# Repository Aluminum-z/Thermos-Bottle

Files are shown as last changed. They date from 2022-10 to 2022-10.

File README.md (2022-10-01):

# Thermos-Bottle
有点鸡肋的恒温杯(盖)第一版, 功率有点小，380ml水需要4h才能够下降10℃ ╮(╯▽╰)╭

## 1. 设计
### 1.1 结构
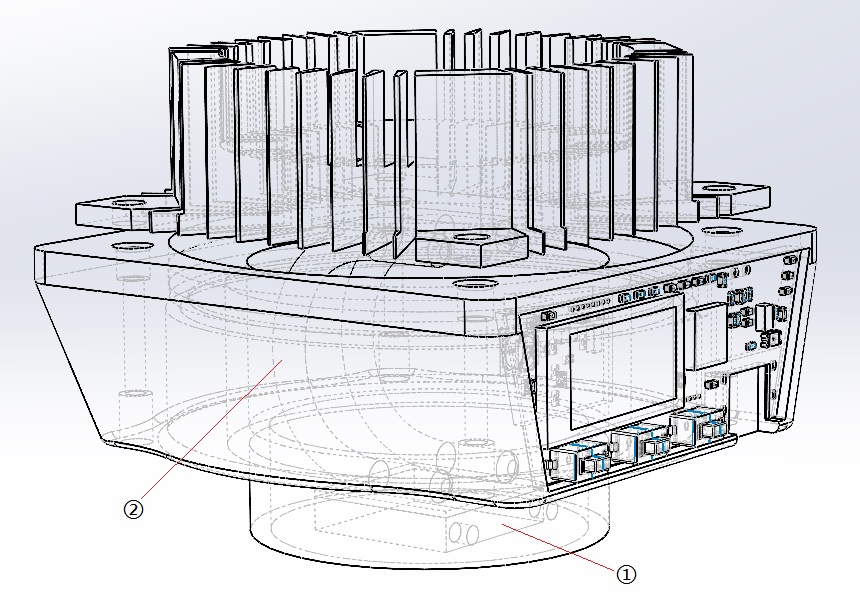
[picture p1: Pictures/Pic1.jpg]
杯盖的3D图


恒温杯盖的结构如上图，其中①所指的方块为半导体制冷片，②为热管。其原理很简单，制冷片的上方与热管紧贴，下方与杯盖内部的金属部分紧贴(①所指的圆柱突出部分在杯子盖起时会深入保温杯内部)。  
1. 当制冷片正向通电时，其下方从杯内吸收热量，上方从杯外放出热量，保温杯处于制冷模式。
2. 当制冷片反向通电时，其上方从杯外吸收热量，下方从杯内放出热量，保温杯处于制热模式。

### 1.2 硬件
电路框图

电路如上图，半导体制冷片串联电感使其变为感性负载，由全桥驱动芯片DRV8837驱动(~~比较便宜~~实际电路中使用两片并联以降低温升)，驱动方式类似于Buck降压电路，当全桥芯片导通时经由制冷片给电感充电，当全桥芯片关断(两输出引脚同时接地，类似同步整流)时由电感给半导体制冷片续流，使得制冷片在开关周期内能够保持一个较为稳定的电流。

注：电路板中的0Ω电阻R7原为复位按钮，请勿焊接。

### 1.3 软件
软件主要分为三个线程，UI线程、Main线程和Idle线程。UI负责处理按键消息和绘制用户界面；Main线程负责定时读取温度、读取输出电压、计算输出功率、根据当前温度调整输出占空比和将相关参数发给UI等工作；Idle线程负责按键的扫描工作。

## 2. 使用说明
### 2.1 界面
界面设计图  
界面设计如上图，其中：
- 左侧为半导体制冷片的工作状态及其两端温度，图中下冷上热三角指向上方即处于制冷状态；
- 进度条TE为半导体制冷片的输出占空比；
- 进度条FN为风扇的输出占空比；
- 右上角STAT处显示当前的工作状态，ON为工作中，OFF为停止；
- 右上角MOD处显示当前的工作模式，STAT为恒温模式，MXC为最大功率制冷模式，MXH为最大功率制热模式；
- 右上角VAL处显示恒温模式的温度设定值；
- 右下角5.0V显示当前的输入电压；
- 右下角3.0W显示当前的制冷片功率(估计值)。

### 2.2 操作
电路板上共有三个按键，从左至右分别“模式”，“加”和“减”；
- 长按“模式”后，进入模式设置状态，此时按下“加”或“减”按键可在“恒温”、“最大制冷功率”和“最大制热功率”间循环切换，模式设置完成后，再次点击“模式”按钮退出；
- 在非模式设置状态下，短按“模式”按钮可以切换当前的工作状态(ON/OFF)；
- 在非模式设置状态下，且当前模式为恒温模式时，点击“加”或“减”按钮可以调整恒温温度，长按“加”或“减”可以快速调整恒温温度。

## 3. 其他
### 3.1 参数
- 电压：5.0V
- 电流：2.0A Max
- 最大制冷功率：8W

### 3.2 待办
- 改进电路设计：
  - 增加快充的支持
  - 使用更大功率的制冷片
  - 调整功率元件至单独的铝基板，并使其能够贴在散热片上
- 改进结构设计：
  - 加一个上盖
  - 解决制冷模式下盖子内部积水的问题
  - 解决当保温杯内的水没有接触杯盖时制冷效率低的问题
  - 解决制热效率低的问题

### 3.3 实物图
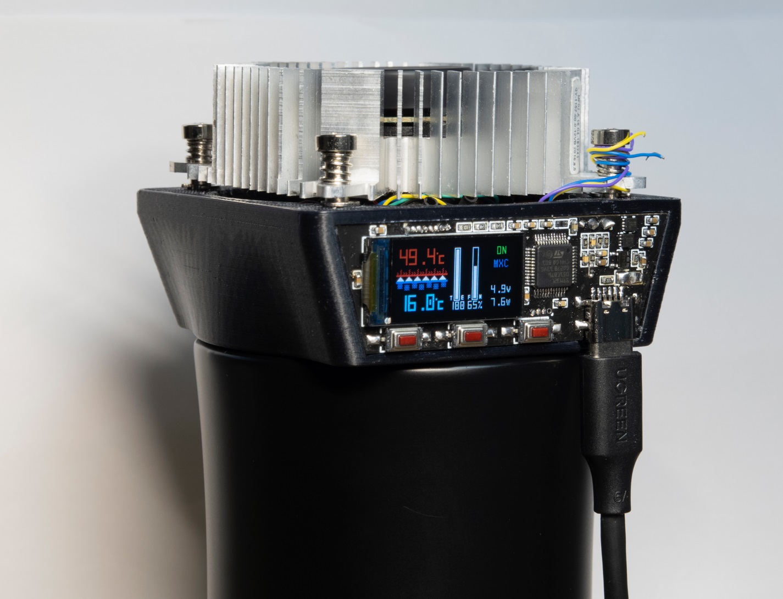
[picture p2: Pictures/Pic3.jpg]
实物图


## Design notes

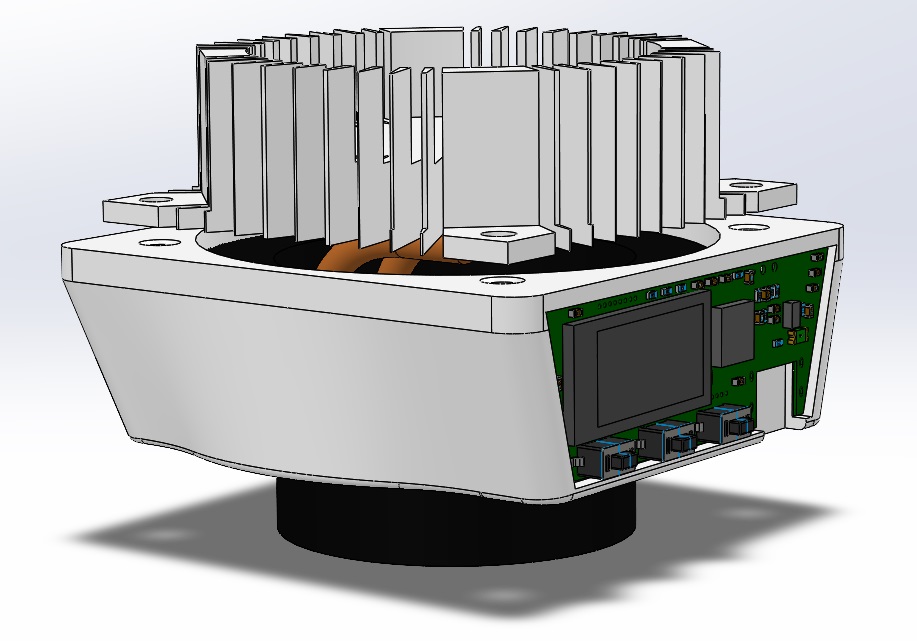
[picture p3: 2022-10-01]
Pictures/Pic2.jpg

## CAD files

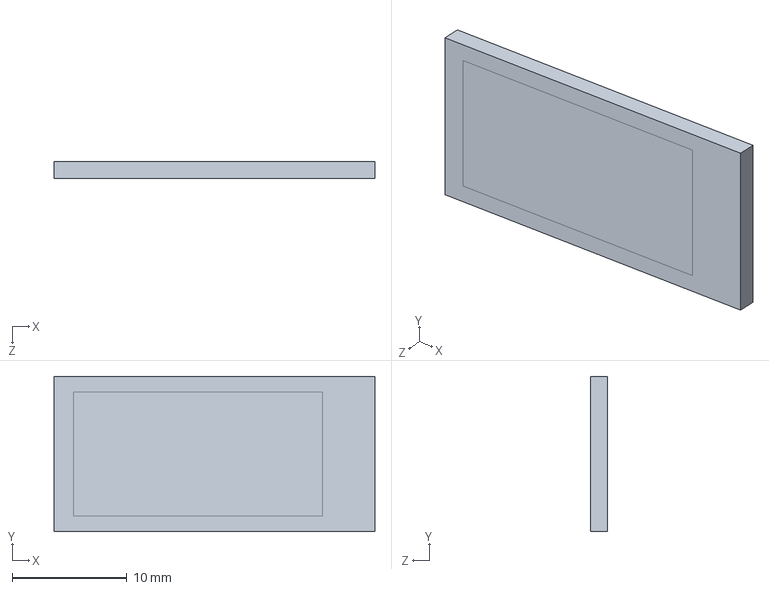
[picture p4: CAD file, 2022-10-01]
Hardware/Construction/LCD.SLDPRT
28.0 x 13.5 x 1.50 mm

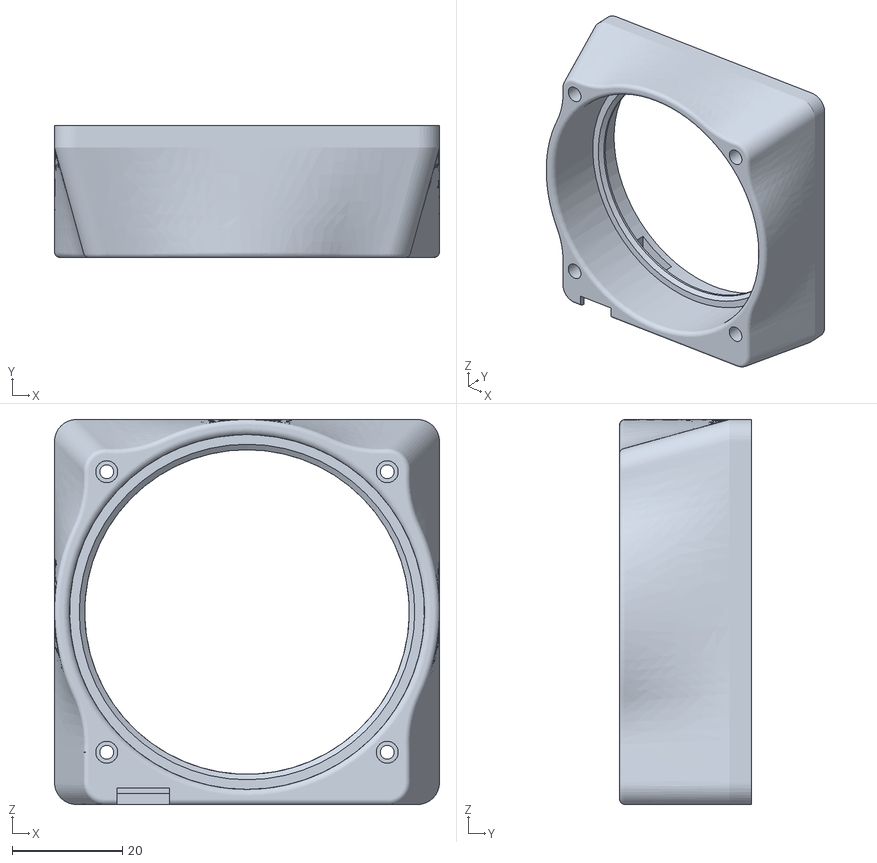
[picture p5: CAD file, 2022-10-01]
Hardware/Construction/Output/LidBottomV2P1.STL
70.0 x 24.0 x 70.0

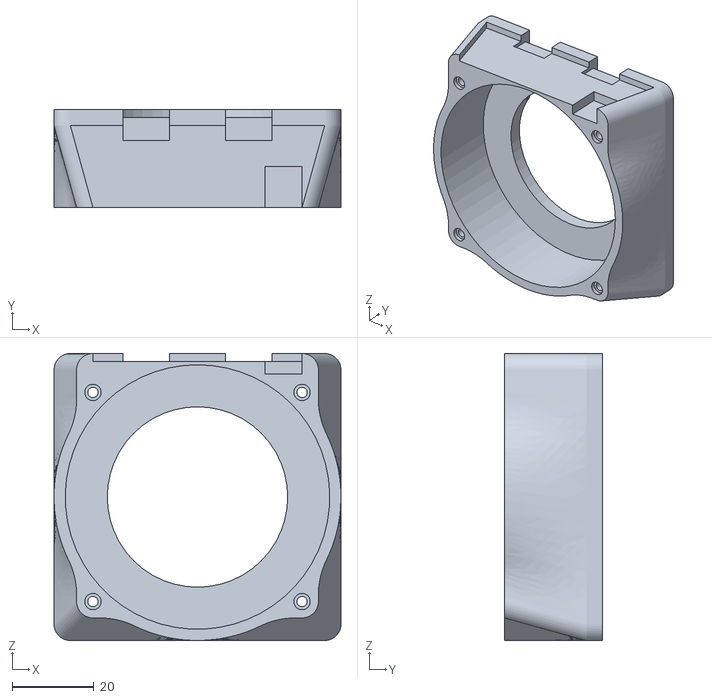
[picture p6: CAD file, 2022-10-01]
Hardware/Construction/Output/LidBottom.STL
70.0 x 24.0 x 70.0

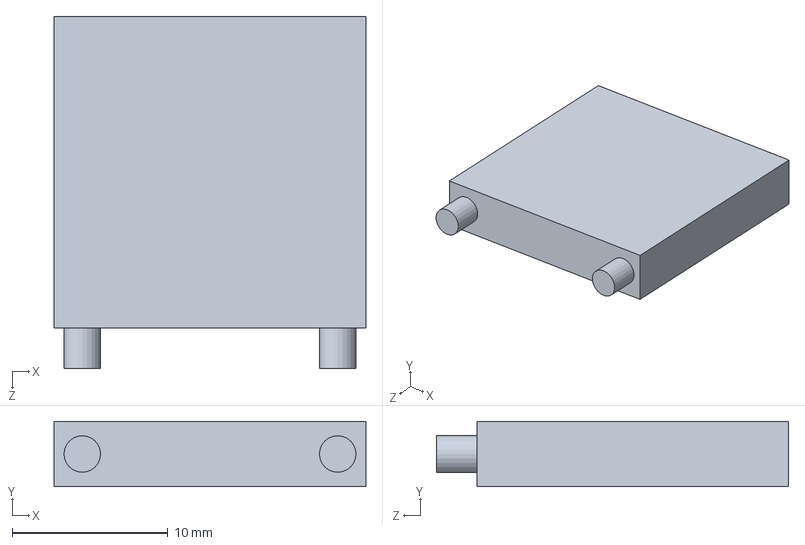
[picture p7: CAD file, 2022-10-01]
Hardware/Construction/TE.SLDPRT
20.0 x 4.20 x 22.6 mm

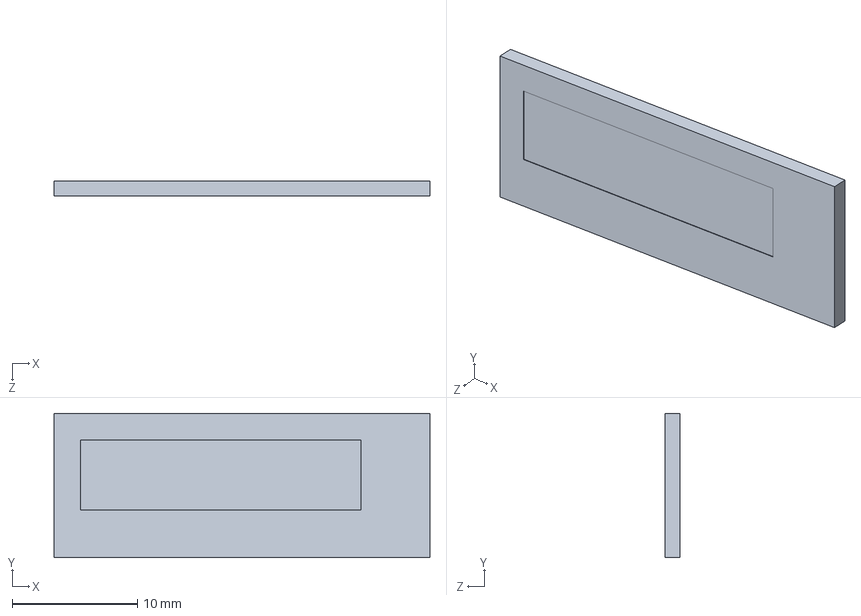
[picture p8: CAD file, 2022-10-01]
Hardware/Construction/OLED.SLDPRT
30.0 x 11.5 x 1.20 mm

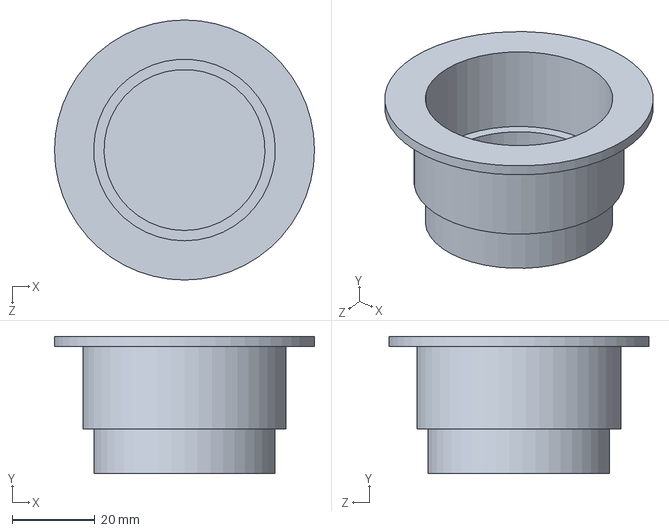
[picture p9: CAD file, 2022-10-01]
Hardware/Construction/LidBase.SLDPRT
63.0 x 33.3 x 63.0 mm

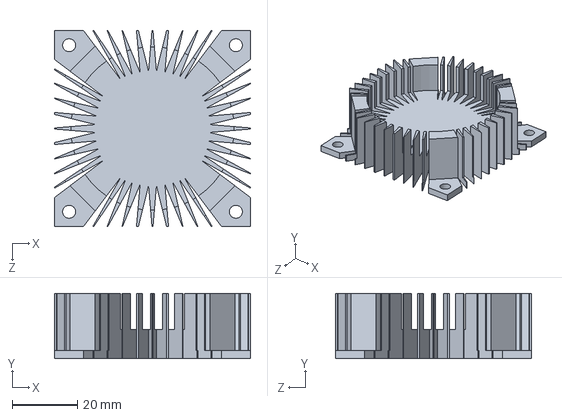
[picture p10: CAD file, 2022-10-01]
Hardware/Construction/Cooler.SLDPRT
60.0 x 20.0 x 60.0 mm

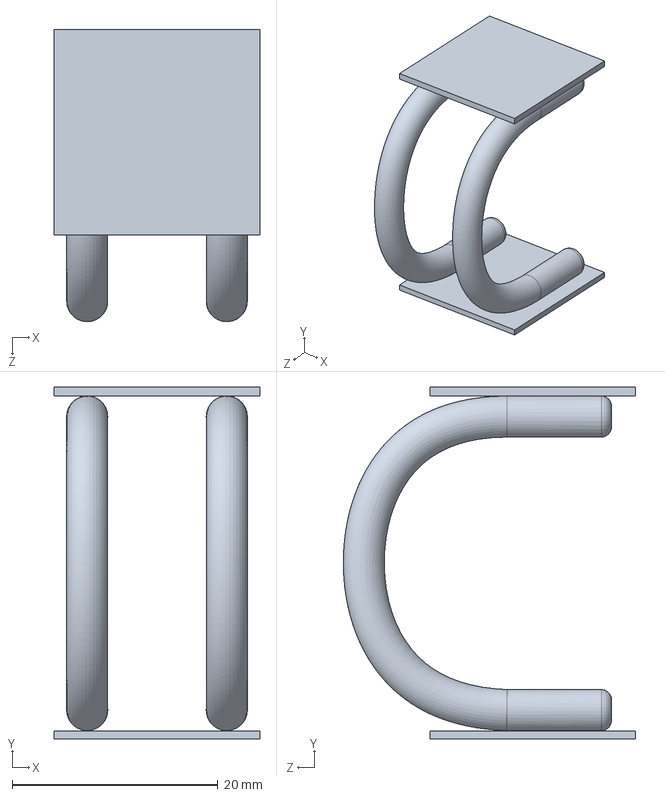
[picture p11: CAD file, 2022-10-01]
Hardware/Construction/Heat-Pipe.SLDPRT
20.0 x 34.3 x 28.4 mm

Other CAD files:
Hardware/Construction/LidBottom.SLDPRT
Hardware/Construction/LidBottomV2P1.SLDPRT

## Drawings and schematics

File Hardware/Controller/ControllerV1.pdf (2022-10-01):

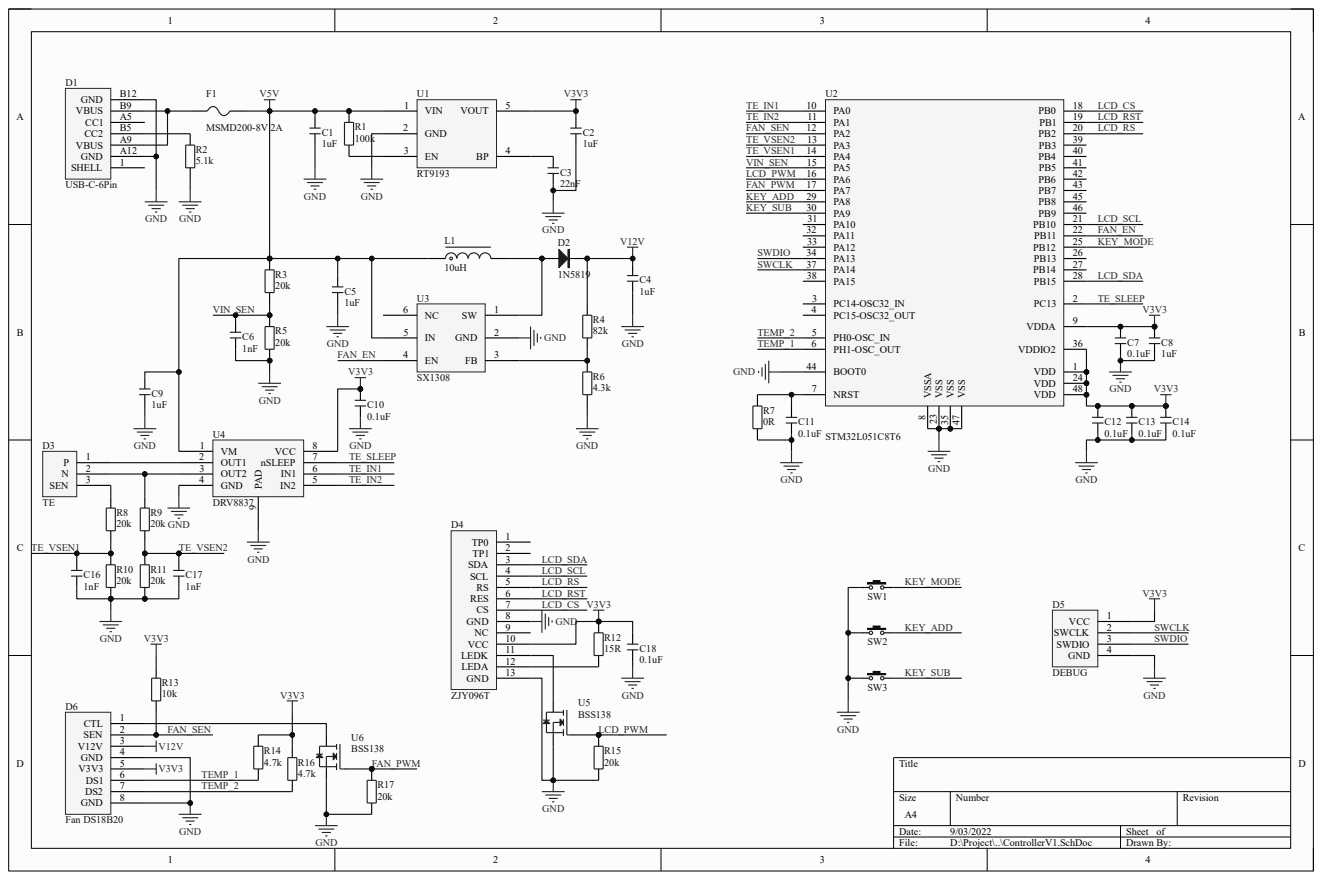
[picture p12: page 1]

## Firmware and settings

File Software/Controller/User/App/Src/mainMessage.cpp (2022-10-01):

/**************************************************************
 * @file    mainMessage.cpp
 * @brief   Message manager for main thread.
 * @author  Alzn
 * @date    2022-09-04
 *************************************************************/

#include "FreeRTOS.h"
#include "timers.h"

#include "deviceManager.hpp"
#include "mainMessage.hpp"
#include "pid.hpp"

#include <cmath>

/**
 * @brief   Callback function for main timer.
 * @author  Alzn
 * @date    2022-09-04
 */
static void mainTimerCallback(TimerHandle_t xTimer) {
  MainMessage &mainMsg = MainMessage::getInstance();
  mainMsg.send(MainMessage::MsgType::MainTimer, 0);
}

class MainMsgHandler {
private:
  enum TickDiv {
    TickTemp,
    TickPwrOut = 5,
    TickPwrIn = 9,
    TickMax = 10,
  };

private:
  TimerHandle_t mTimerHandle;

  uint16_t mTick;

  float mVolIn;
  float mCurTe;

  float mTempBtm;
  float mTempTop;

  bool mIsPwrEnabled;
  WorkMode mWorkMode;
  float mCfgTemp;

  Pid<float> mPidTec;
  TecMode mTecMode;

  bool mIsUiSynced;

private:
  MainMsgHandler &operator=(const MainMsgHandler &) = delete;
  MainMsgHandler(const MainMsgHandler &) = delete;
  MainMsgHandler() {
    mIsPwrEnabled = false;
    mTick = 0;
    mIsUiSynced = false;
  }

  void restartMainTimer(void) {
    xTimerStart(mTimerHandle, 0);
  }

  void sendValueToUI(UiMessage::MsgType msgType, float value1, float value2) {
    UiMessage &uiMsg = UiMessage::getInstance();
    UiMessage::MsgDataFloat msgData;
    msgData.data1 = value1;
    msgData.data2 = value2;
    uiMsg.send(msgType, msgData);
  }

  void setTecMode(TecMode mode) {
    if (mTecMode == mode) {
      return;
    }
    mTecMode = mode;
    DeviceManager &deviceManager = DeviceManager::getInstance();
    Tec &tec = deviceManager.getTec();
    tec.setMode(mTecMode);
    UiMessage &uiMsg = UiMessage::getInstance();
    uiMsg.send(UiMessage::MsgType::TecMode, mTecMode);
  }

public:
  static MainMsgHandler &getInstance(void) {
    static MainMsgHandler instance;
    return instance;
  }

  void init(void) {
    /* Variable */
    mVolIn = 0.0f;
    mCurTe = 0.0f;
    mTempBtm = 0.0f;
    mTempTop = 0.0f;

    mPidTec.setFactor(0.05f, 0.0005f, 0.02f);
    mPidTec.setCtrlValLimit(-1.0f, 1.0f);
    mPidTec.reset(0.0f);

    mTecMode = TecMode::BtmCoolTopHeat;
    mWorkMode = WorkMode::Thermostat;
    mCfgTemp = 20.0f;
    mIsUiSynced = false;
    /* Hardware */

    /* Timer */
    mTimerHandle = xTimerCreate("Main", pdMS_TO_TICKS(100), pdFALSE, nullptr, mainTimerCallback);
    restartMainTimer();
  }

  void mainTimerHandler(void) {
    mTick++;
    if (mTick >= TickMax) {
      mTick = 0;
    }

    restartMainTimer();

    if (!mIsUiSynced) {
      UiMessage &uiMsg = UiMessage::getInstance();
      uiMsg.send<UiMessage::MsgDataModeAndValue>(UiMessage::MsgType::WorkModeAndValue, {mCfgTemp, mWorkMode});
    }

    DeviceManager &deviceManager = DeviceManager::getInstance();
    Adc &adc = deviceManager.getAdc();
    if (!adc.getIsConverting()) {
      adc.start();
    }
    if (mTick == TickPwrIn) {
      sendValueToUI(UiMessage::MsgType::PowerIn, mVolIn, mCurTe);
    }

    Ds18b20 &tempsenTop = deviceManager.getTempSenTop();
    Ds18b20 &tempSenBtm = deviceManager.getTempSenBtm();
    mTempTop = tempsenTop.readTemp();
    mTempBtm = tempSenBtm.readTemp();
    if (mTick == TickTemp) {
      sendValueToUI(UiMessage::MsgType::Temperatures, mTempTop, mTempBtm);
    }

    float fanPwr = 0.0f;
    float tecPwr = 0.0f;
    if (!mIsPwrEnabled) {
      tecPwr = 0.0f;
      fanPwr = 0.0f;
    } else {
      mPidTec.setMeaVal(mTempBtm);
      if (mTecMode == TecMode::BtmCoolTopHeat) {
        if (mPidTec.getCtrlVal() > 0.01f) {
          setTecMode(TecMode::BtmHeatTopCool);
        }
      } else {
        if (mPidTec.getCtrlVal() < -0.01f) {
          setTecMode(TecMode::BtmCoolTopHeat);
        }
      }
      tecPwr = fabsf(mPidTec.getCtrlVal());
      if (mTecMode == TecMode::BtmCoolTopHeat) {
        const float maxTemperature = 60.0f;
        const float fanThreshold = 30.0f;
        if (mTempTop < fanThreshold) {
          fanPwr = 0.0f;
        } else {
          fanPwr = (mTempTop - fanThreshold) * (1.0f / (maxTemperature - fanThreshold));
          if (fanPwr > 1.0f) {
            fanPwr = 1.0f;
          }
        }
      } else {
        const float minTemperature = 0.0f;
        const float fanThreshold = 20.0f;
        if (mTempTop > fanThreshold) {
          fanPwr = 0.0f;
        } else {
          fanPwr = (fanThreshold - mTempTop) * (1.0f / (fanThreshold - minTemperature));
          if (fanPwr > 1.0f) {
            fanPwr = 1.0f;
          }
        }
      }
    }
    Tec &tec = deviceManager.getTec();
    tec.setDutyCycle(tecPwr);
    Fan &fan = deviceManager.getFan();
    fan.setDutyCycle(fanPwr);

    if (mTick == TickPwrOut) {
      sendValueToUI(UiMessage::MsgType::PowerOut, tecPwr, fanPwr);
    }
  }

  void adcConvCpltHandler(void) {
    DeviceManager &deviceManager = DeviceManager::getInstance();
    Adc &adc = deviceManager.getAdc();
    adc.convCpltCallBack();
    mVolIn = adc.getValue(Adc::AdcValVin);
    mCurTe = adc.getValue(Adc::AdcValPwr);
  }

  void setIsPwrEnabled(bool isEnabled) {
    if (mIsPwrEnabled == isEnabled) {
      return;
    }
    mIsPwrEnabled = isEnabled;
    if (isEnabled) {
      switch (mWorkMode) {
        case WorkMode::Thermostat:
          mPidTec.setCfgMeaVal(mCfgTemp);
          break;

        case WorkMode::MaxPwrCool:
          mPidTec.setCfgMeaVal(0.0f);
          break;

        case WorkMode::MaxPwrHeat:
          mPidTec.setCfgMeaVal(80.0f);
          break;

        default:
          break;
      }
    }
    mPidTec.reset(0.0f);
    UiMessage &uiMsg = UiMessage::getInstance();
    uiMsg.send(UiMessage::MsgType::PowerIsEnable, isEnabled);
  }

  void setWorkMode(WorkMode mode) {
    if (mWorkMode == mode) {
      return;
    }
    mWorkMode = mode;
    setIsPwrEnabled(false);
    UiMessage &uiMsg = UiMessage::getInstance();
    uiMsg.send<UiMessage::MsgDataModeAndValue>(UiMessage::MsgType::WorkModeAndValue, {mCfgTemp, mWorkMode});
  }

  void setCtrlValue(float value) {
    if (mWorkMode != WorkMode::Thermostat) {
      return;
    }
    const float maxTemp = 80.0f;
    const float minTemp = 0.0f;
    if (value > maxTemp) {
      value = maxTemp;
    }
    if (value < minTemp) {
      value = minTemp;
    }
    if (mCfgTemp == value) {
      return;
    }
    mCfgTemp = value;
    mPidTec.setCfgMeaVal(value);
    UiMessage &uiMsg = UiMessage::getInstance();
    uiMsg.send<UiMessage::MsgDataModeAndValue>(UiMessage::MsgType::WorkModeAndValue, {mCfgTemp, mWorkMode});
  }
};

/**
 * @brief   Get the unique instance.
 * @author  Alzn
 * @date    2022-04-07
 */
MainMessage &MainMessage::getInstance(void) {
  static MainMessage instance;
  return instance;
}

/**
 * @brief   Initialize the message meanager.
 * @author  Alzn
 * @date    2022-04-07
 */
void MainMessage::init(void) {
  initQueue(8, sizeof(MsgStruct));
  MainMsgHandler &mainMsgHandler = MainMsgHandler::getInstance();
  mainMsgHandler.init();
}

/**
 * @brief   Waitting for messages and handle one.
 * @author  Alzn
 * @date    2022-04-07
 */
void MainMessage::waitAndHandle(void) {
  MsgStruct msgStruct;
  receiveElement(&msgStruct);
  MainMsgHandler &mainMsgHandler = MainMsgHandler::getInstance();
  switch (msgStruct.msgType) {
    case MsgType::MainTimer:
      mainMsgHandler.mainTimerHandler();
      break;

    case MsgType::AdcConvCplt:
      mainMsgHandler.adcConvCpltHandler();
      break;

    case MsgType::IsPwrEnabled:
      mainMsgHandler.setIsPwrEnabled(getMsgData<bool>(msgStruct));
      break;

    case MsgType::WorkMode:
      mainMsgHandler.setWorkMode(getMsgData<WorkMode>(msgStruct));
      break;

    case MsgType::CtrlValue:
      mainMsgHandler.setCtrlValue(getMsgData<float>(msgStruct));
      break;

    default:
      break;
  }
}

/* END OF FILE */

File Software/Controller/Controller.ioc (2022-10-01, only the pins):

Mcu.UserName=STM32L051C8Tx
PA0.Signal=S_TIM2_CH1
PA1.Signal=S_TIM2_CH2
PA13.Signal=SYS_SWDIO
PA14.Signal=SYS_SWCLK
PA2.Signal=S_TIM21_CH1
PA3.Signal=ADC_IN3
PA4.Signal=ADC_IN4
PA5.Signal=ADC_IN5
PA6.Signal=S_TIM22_CH1
PA7.Signal=S_TIM22_CH2
PA8.GPIO_Label=KEY_ADD
PA8.Signal=GPIO_Input
PA9.GPIO_Label=KEY_SUB
PA9.Signal=GPIO_Input
PB0.GPIO_Label=LCD_CS
PB0.Signal=GPIO_Output
PB1.GPIO_Label=LCD_RST
PB1.Signal=GPIO_Output
PB10.Signal=SPI2_SCK
PB11.GPIO_Label=FAN_EN
PB11.Signal=GPIO_Output
PB12.GPIO_Label=KEY_MODE
PB12.Signal=GPIO_Input
PB15.Signal=SPI2_MOSI
PB2.GPIO_Label=LCD_RS
PB2.Signal=GPIO_Output
PC13.GPIO_Label=TE_SLEEP
PC13.Signal=GPIO_Output
PH0-OSC_IN.GPIO_Label=TEMP2
PH0-OSC_IN.Signal=GPIO_Output
PH1-OSC_OUT.GPIO_Label=TEMP1
PH1-OSC_OUT.Signal=GPIO_Output

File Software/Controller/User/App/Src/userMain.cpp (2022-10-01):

/**************************************************************
 * @file    userMain.cpp
 * @brief   User main task.
 * @author  Alzn
 * @date    2022-03-28
 *************************************************************/

/* Include */
#include "FreeRTOS.h"
#include "task.h"

#include "deviceManager.hpp"
#include "logging.hpp"
#include "mainMessage.hpp"
#include "uiMain.hpp"
#include "uiMessage.hpp"

extern "C" {
/**
 * @brief   Main thread function.
 * @author  Alzn
 * @date    2022-09-12
 */
void mainThread(void *pPara) {
  MainMessage &mainMsg = MainMessage::getInstance();
  mainMsg.init();

  createUiThread();

  while (true) {
    mainMsg.waitAndHandle();
  }
}

/**
 * @brief   User main function.
 * @author  Alzn
 * @date    2022-03-28
 */
void userMain(void) {
  DeviceManager &deviceManager = DeviceManager::getInstance();
  deviceManager.init();

  LOG("Init done, create threads and start kernel...");

  xTaskCreate(mainThread, "Main", 164, nullptr, 2, nullptr);
  __HAL_TIM_CLEAR_IT(&htim6, TIM_IT_UPDATE);
  __HAL_TIM_ENABLE_IT(&htim6, TIM_IT_UPDATE);
  __HAL_TIM_ENABLE(&htim6);
  vTaskStartScheduler();
}

/**
 * @brief   Timer 6 update interrupt callback function.
 * @author  Alzn
 * @date    2022-09-12
 */
void TIM6_DAC_IRQHandler(void) {
  __HAL_TIM_CLEAR_IT(&htim6, TIM_IT_UPDATE);
  xPortSysTickHandler();
}

/**
 * @brief   Adc convert complete callback function.
 * @author  Alzn
 * @date    2022-09-04
 */
void HAL_ADC_ConvCpltCallback(ADC_HandleTypeDef *hadc) {
  MainMessage &mainMsg = MainMessage::getInstance();
  mainMsg.send(MainMessage::MsgType::AdcConvCplt, 0, true);
}

/**
 * @brief   Hook function for idle thread.
 * @author  Alzn
 * @date    2022-09-14
 */
void vApplicationIdleHook(void) {
  DeviceManager &deviceManager = DeviceManager::getInstance();
  deviceManager.getKeyMod().check();
  deviceManager.getKeyAdd().check();
  deviceManager.getKeySub().check();
}
}

/* END OF FILE */

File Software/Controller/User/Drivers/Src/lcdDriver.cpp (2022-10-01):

/**************************************************************
 * @file    lcdDriver.cpp
 * @brief   Lcd driver.
 * @author  Alzn
 * @date    2022-03-28
 *************************************************************/

#include "lcdDriver.hpp"

namespace Lcd {

/**
 * @brief   Constructor
 * @author  Alzn
 * @date    2022-03-28
 */
LcdDriver::LcdDriver(void) {
  mPtrChip = nullptr;
}

/**
 * @brief   Constructor with device information.
 * @author  Alzn
 * @date    2022-03-28
 * @note    This function mast be called befor initialization.
 */
LcdDriver::LcdDriver(const DeviceInfo &deviceInfo) {
  mPtrChip = deviceInfo.mPtrChip;
  mSizeX = deviceInfo.sizeX;
  mSizeY = deviceInfo.sizeY;
  mDispOrientation = deviceInfo.dispOrientation;
  mBacklightPwm = deviceInfo.backlightPwm;
}

/**
 * @brief   Initialize lcd module.
 * @author  Alzn
 * @date    2022-03-28
 */
void LcdDriver::init(void) {
  if (mBacklightPwm.isValid()) {
    mBacklightPwm.init();
    mBacklightPwm.setEnable(true);
    mBacklightPwm.setDutyCycle(0.0f);
  }
  mPtrChip->init();
  setDispOrientation(mDispOrientation);
  clear(0x0000);
  clear(0x0000); /* Make sure the LCD is updated before turning on the backlight. */
  if (mBacklightPwm.isValid()) {
    mBacklightPwm.setDutyCycle(0.5f);
  }
}

/**
 * @brief   Clear screen
 * @author  Alzn
 * @date    2022-03-28
 */
void LcdDriver::clear(uint16_t color) {
  drawBlock(0, 0, mSizeX, mSizeY, color);
}

/**
 * @brief   Set backlight in percentage.
 * @author  Alzn
 * @date    2022-03-29
 */
void LcdDriver::setBacklight(float lightPct) {
  if (mBacklightPwm.isValid()) {
    mBacklightPwm.setDutyCycle(lightPct);
  }
}

/**
 * @brief   Set backlight in percentage.
 * @author  Alzn
 * @date    2022-03-29
 * @param   newOrientation The new orientation you want to change to. @ref DispOrientation
 */
void LcdDriver::setDispOrientation(DispOrientation newOrientation) {
  mPtrChip->setOrientation(newOrientation);
  if ((mDispOrientation == DispOrientation::Horizontal || mDispOrientation == DispOrientation::HoriWithFlip)
      != (newOrientation == DispOrientation::Horizontal || newOrientation == DispOrientation::HoriWithFlip)) {
    uint32_t tempSize = mSizeX;
    mSizeX = mSizeY;
    mSizeY = tempSize;
  }
  mDispOrientation = newOrientation;
}

/**
 * @brief   Get binary image of specified character from font.
 * @author  Alzn
 * @date    2022-04-09
 */
const uint8_t *LcdDriver::getCharFontImage(char value, const FontType &font) {
  if ((value >= font.charStart) && (value <= font.charEnd)) {
    return font.pData + (value - font.charStart) * font.bytePerChar;
  }
  return nullptr;
}

/**
 * @brief   Get specified bit in binary image.
 * @author  Alzn
 * @date    2022-04-09
 * @note    This function is not effective.
 */
bool LcdDriver::getBinaryImageBit(uint16_t x, uint16_t y, uint16_t widget, uint16_t height, const uint8_t *pImage) {
  pImage += y * widget / 8;
  if ((widget % 8) != 0) {
    pImage += y;
  }
  pImage += x / 8;
  x %= 8;
  return (*pImage & (0x80 >> x)) != 0;
}

/**
 * @brief   Fill a block.
 * @author  Alzn
 * @date    2022-03-29
 */
void LcdDriver::drawBlock(uint16_t x, uint16_t y, uint16_t width, uint16_t height, uint16_t color) {
  mPtrChip->setRange(x, x + width - 1, y, y + height - 1);
  mPtrChip->fillColor(color, width * height);
}

/**
 * @brief   Connect line.
 * @author  Alzn
 * @date    2022-03-29
 * @param   x1    Start x
 * @param   y1    Start y
 * @param   x2    End x
 * @param   y2    End y
 * @param   color
 */
void LcdDriver::drawLine(uint16_t x1, uint16_t y1, uint16_t x2, uint16_t y2, uint16_t color) {
  int32_t incX, incY, d, dAddPos, dAddNeg;
  int32_t x, y, step;
  incX = x2 - x1;
  incY = y2 - y1;
  if (incX == 0) {
    if (incY > 0) {
      drawVertLine(x1, y1, 1 + incY, color);
    } else {
      drawVertLine(x1, y1 + incY, 1 - incY, color);
    }
    return;
  }
  if (incY == 0) {
    if (incX > 0) {
      drawHoriLine(x1, y1, 1 + incX, color);
    } else {
      drawHoriLine(x1 + incX, y1, 1 - incX, color);
    }
    return;
  }
  if (incX < 0) {
    incX = -incX;
  }
  if (incY < 0) {
    incY = -incY;
  }
  if (incX > incY) {
    if (x1 > x2) {
      x1 -= incX;
      x2 += incX;
      y = y2;
      y2 = y1;
      y1 = y;
    }
    d = -incX;
    dAddPos = 2 * (incY - incX);
    dAddNeg = 2 * incY;
    step = (y1 < y2) ? 1 : -1;
    x = x1;
    y = y1;
    mPtrChip->setRange(x, mSizeX, y, y);
    for (x = x1; x <= x2; x++) {
      mPtrChip->writeColor(color);
      if (d > 0) {
        y += step;
        d += dAddPos;
        mPtrChip->setRange(x, mSizeX, y, y);
      } else {
        d += dAddNeg;
      }
    }
  } else {
    if (y1 > y2) {
      y1 -= incY;
      y2 += incY;
      x = x2;
      x2 = x1;
      x1 = x;
    }
    d = -incY;
    dAddPos = 2 * (incX - incY);
    dAddNeg = 2 * incX;
    step = (x1 < x2) ? 1 : -1;
    x = x1;
    y = y1;
    mPtrChip->setRange(x, x, y, mSizeY);
    for (y = y1; y <= y2; y++) {
      mPtrChip->writeColor(color);
      if (d > 0) {
        x += step;
        d += dAddPos;
        mPtrChip->setRange(x, x, y, mSizeY);
      } else {
        d += dAddNeg;
      }
    }
  }
}
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
